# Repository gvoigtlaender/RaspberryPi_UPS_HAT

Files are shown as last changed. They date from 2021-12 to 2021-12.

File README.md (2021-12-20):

# RaspberryPi_UPS_HAT
## RaspberryPi UPS HAT, LIPO, Fan Control, I2C

## Project goals:
* provide backup battery (LiPo 3.7V) with I2C status interface
* small footprint to integrate into given RaspberrryPi case (LABISTS Starter Kit)
* integrated fan control (temperature based)
* onboard programmer interface (ISP)
* I2C based RPI ups service for Battery supervision, logging and shutdown (systemd, python3, smbus)

## Used items:
* Attiny 841 CPU
* LTC4054 LiPo Charger
* MT3606 Step-Up (LiPo > 5V)
* MIC5219 LDO (5V > 3.3V)
* USB Type-C connector
* resistors, capacitory (SMD 0805)

## Schematic:
schematic

## PCB:
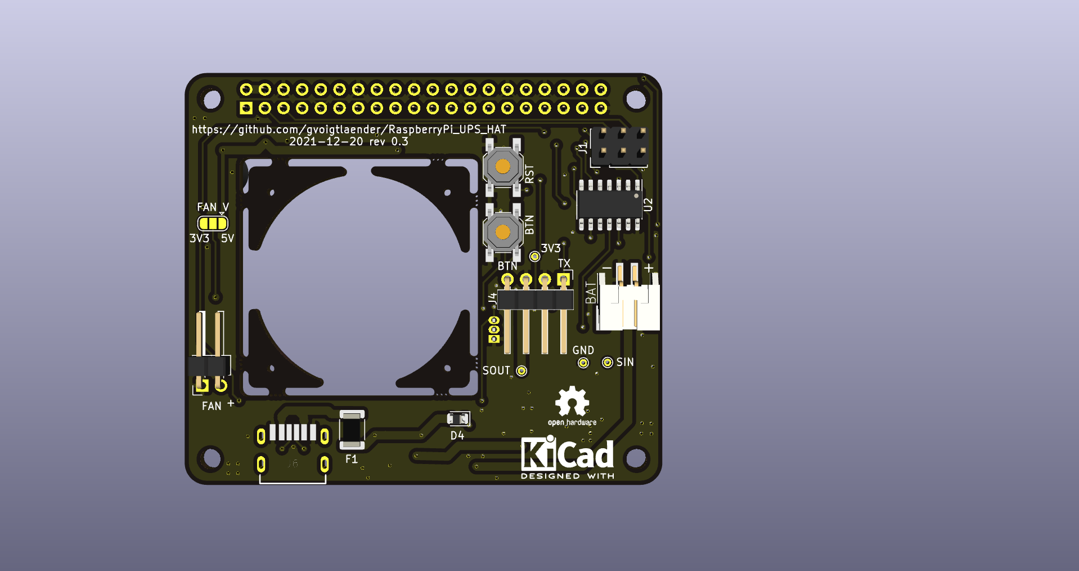
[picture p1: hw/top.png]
top view

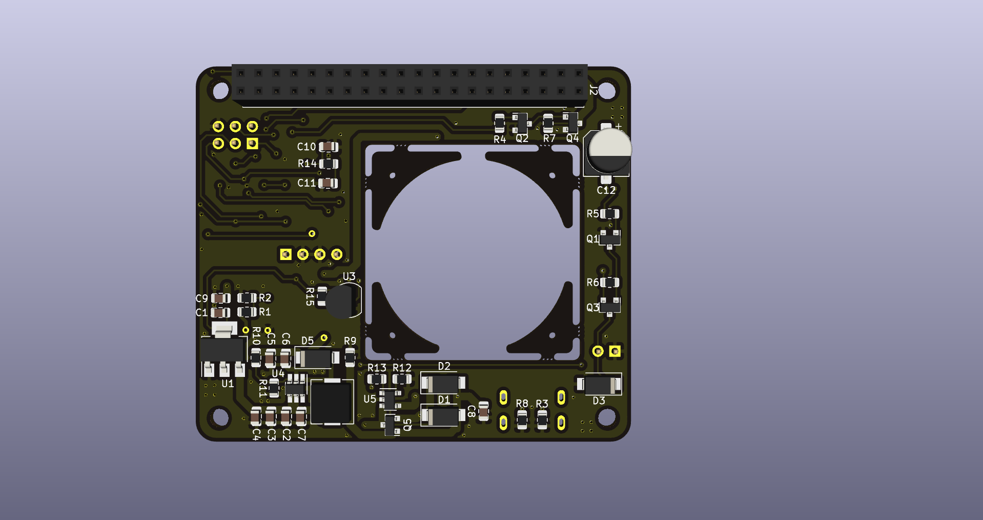
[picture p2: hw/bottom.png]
back view


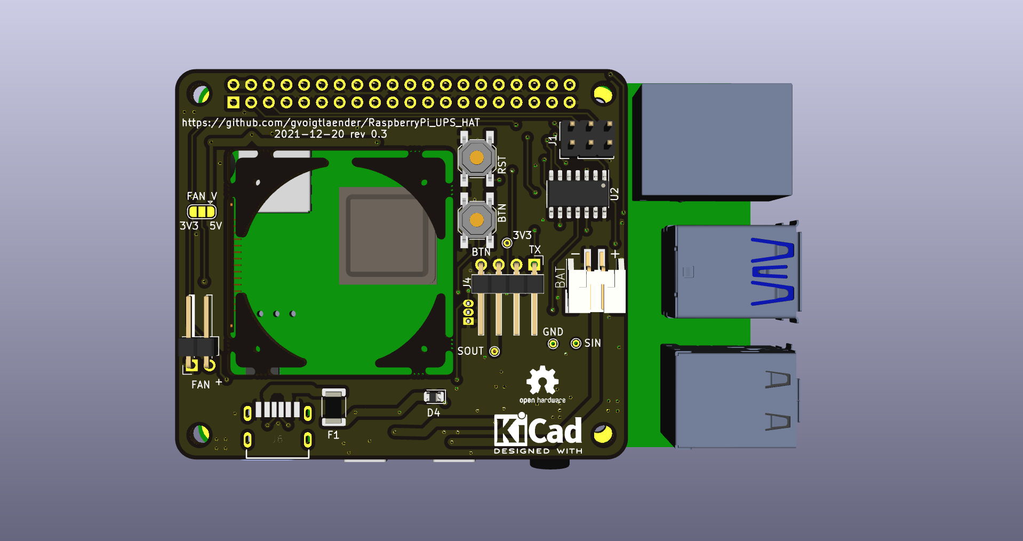
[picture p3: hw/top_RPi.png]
top view with PRi

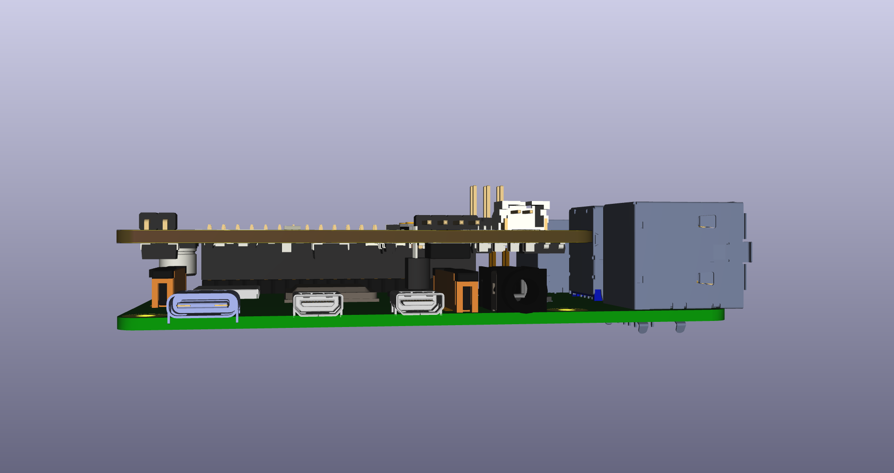
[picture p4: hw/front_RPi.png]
front view with PRi

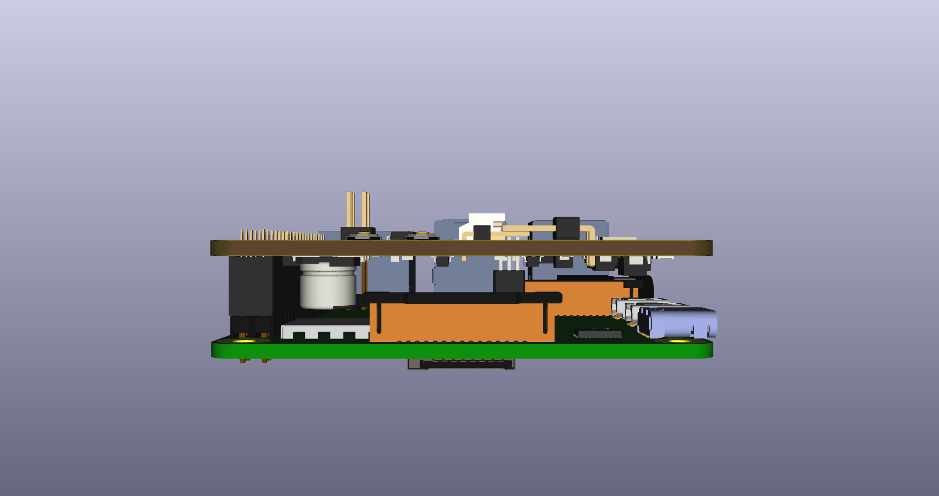
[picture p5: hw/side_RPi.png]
side view with PRi

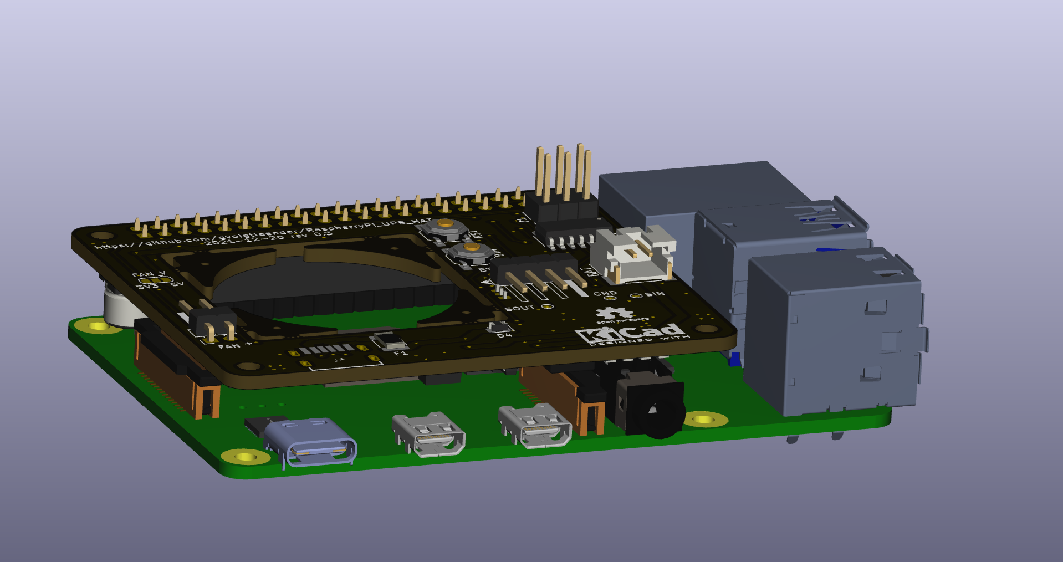
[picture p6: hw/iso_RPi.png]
iso view with PRi


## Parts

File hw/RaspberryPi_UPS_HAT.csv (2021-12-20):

Comment | Designator | Footprint | LCSC | MANUFACTURER | MAXIMUM_PACKAGE_HEIGHT | PARTREV | STANDARD
470pF | C1 | Capacitor_SMD:C_0805_2012Metric
100uF | C12 | Capacitor_SMD:CP_Elec_6.3x5.9
1uF | C2,C8,C9 | Capacitor_SMD:C_0805_2012Metric
22uF | C4,C3,C6,C5 | Capacitor_SMD:C_0805_2012Metric
100nF | C7,C10,C11 | Capacitor_SMD:C_0805_2012Metric
1N5819 | D3,D1,D5,D2 | Diode_SMD:D_SMA
LED | D4 | Diode_SMD:D_0805_2012Metric
Fuse | F1 | Fuse:Fuse_1812_4532Metric
ISP | J1 | Connector_PinHeader_2.54mm:PinHeader_2x03_P2.54mm_Vertical
Raspberry_Pi_2_3 | J2 | RaspberryPi_UPS_HAT:PinSocket_2x20_P2.54mm_Vertical_RPI
BAT | J3 | kicad_parts:JST-PH-2-SMT-RA
COM | J4 | Connector_PinHeader_2.54mm:PinHeader_1x04_P2.54mm_Horizontal
FAN | J5 | Connector_PinHeader_2.54mm:PinHeader_1x02_P2.54mm_Horizontal
USB4125-GF-A_REVA | J6 | kicad_parts:GCT_USB4125-GF-A_REVA |  | GCT | 3.16 mm | Rev A | Manufacturer Recommendations
FAN V | JP1 | Jumper:SolderJumper-3_P1.3mm_Open_RoundedPad1.0x1.5mm
6.8uH | L1 | Inductor_SMD:L_6.3x6.3_H3
BC846 | Q2,Q1 | Package_TO_SOT_SMD:SOT-23
AO3401A | Q3,Q4,Q5 | Package_TO_SOT_SMD:SOT-23
22k | R1 | Resistor_SMD:R_0805_2012Metric
14k | R11 | Resistor_SMD:R_0805_2012Metric
4k7 | R15 | Resistor_SMD:R_0805_2012Metric
33k | R2 | Resistor_SMD:R_0805_2012Metric
10k | R4,R5,R12,R13,R14 | Resistor_SMD:R_0805_2012Metric
100k | R6,R7,R10,R9 | Resistor_SMD:R_0805_2012Metric
5.1k | R8,R3 | Resistor_SMD:R_0805_2012Metric
BTN | SW1 | kicad_parts:SW_SPST_SKQG_WithoutStem
RST | SW2 | kicad_parts:SW_SPST_SKQG_WithoutStem
SIN | TP1 | TestPoint:TestPoint_THTPad_D1.0mm_Drill0.5mm
SOUT | TP2 | TestPoint:TestPoint_THTPad_D1.0mm_Drill0.5mm
GND | TP3 | TestPoint:TestPoint_THTPad_D1.0mm_Drill0.5mm
3V3 | TP4 | TestPoint:TestPoint_THTPad_D1.0mm_Drill0.5mm
AMS1117-3.3 | U1 | Package_TO_SOT_SMD:SOT-223-3_TabPin2
ATtiny841-SSU | U2 | Package_SO:SOIC-14_3.9x8.7mm_P1.27mm
DS18B20 | U3 | Package_TO_SOT_THT:TO-92_Inline
MT3608 | U4 | Package_TO_SOT_SMD:SOT-23-6_Handsoldering
TP4054 | U5 | Package_TO_SOT_SMD:SOT-23-5

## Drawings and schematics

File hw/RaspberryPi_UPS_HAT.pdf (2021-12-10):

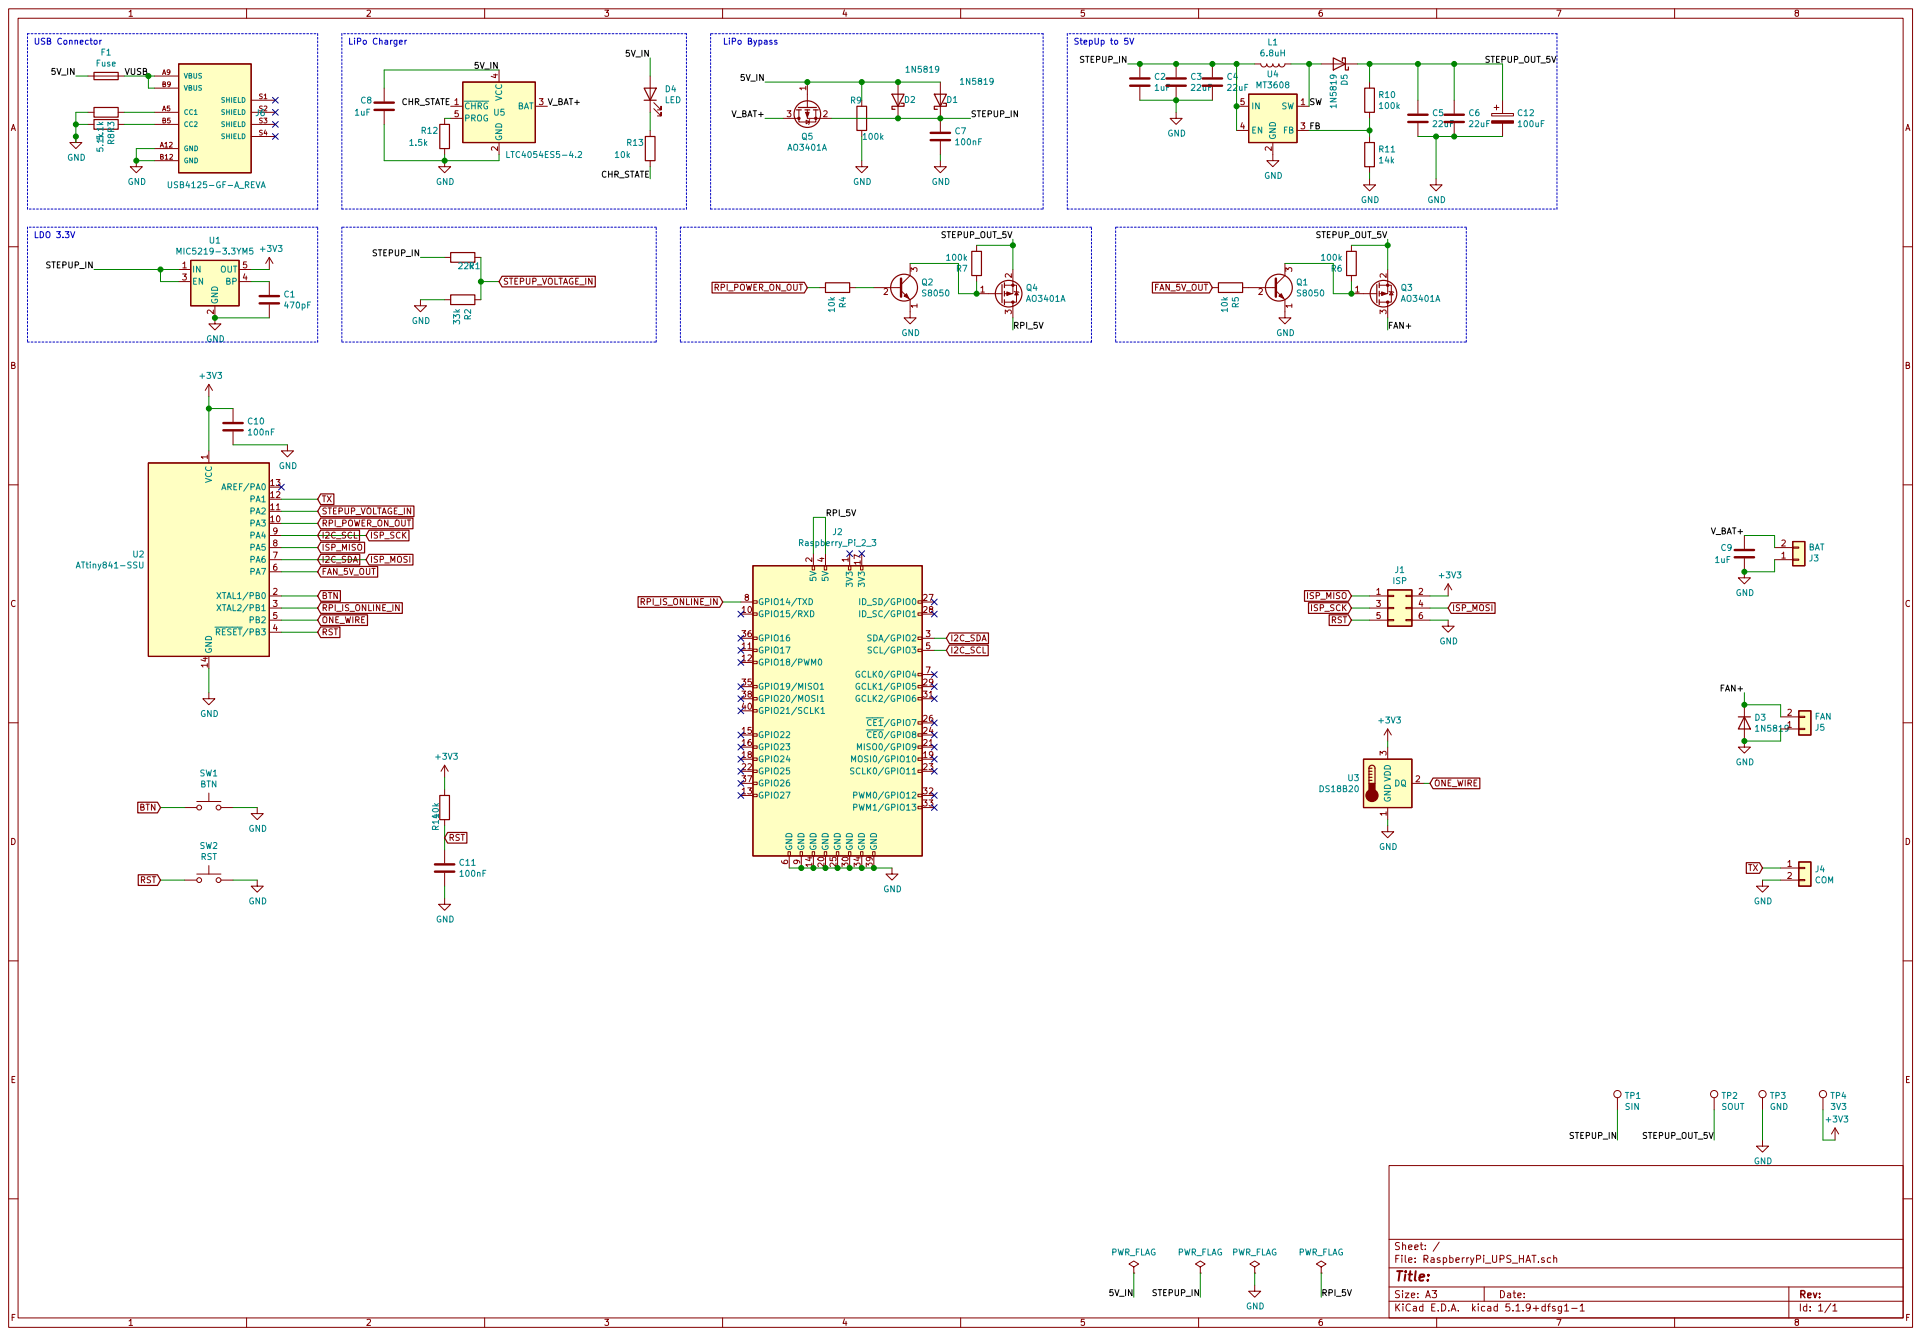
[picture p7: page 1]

1 PA3 10 PA2 11 PA1 12 AREF/PA0 13 GND 14 XTAL1/PB0 2 XTAL2/PB1 3 RESET/PB3 4 PB2 5 PA7 6 PA6 7 PA5 8 PA4 9 U2 ATtiny841-SSU

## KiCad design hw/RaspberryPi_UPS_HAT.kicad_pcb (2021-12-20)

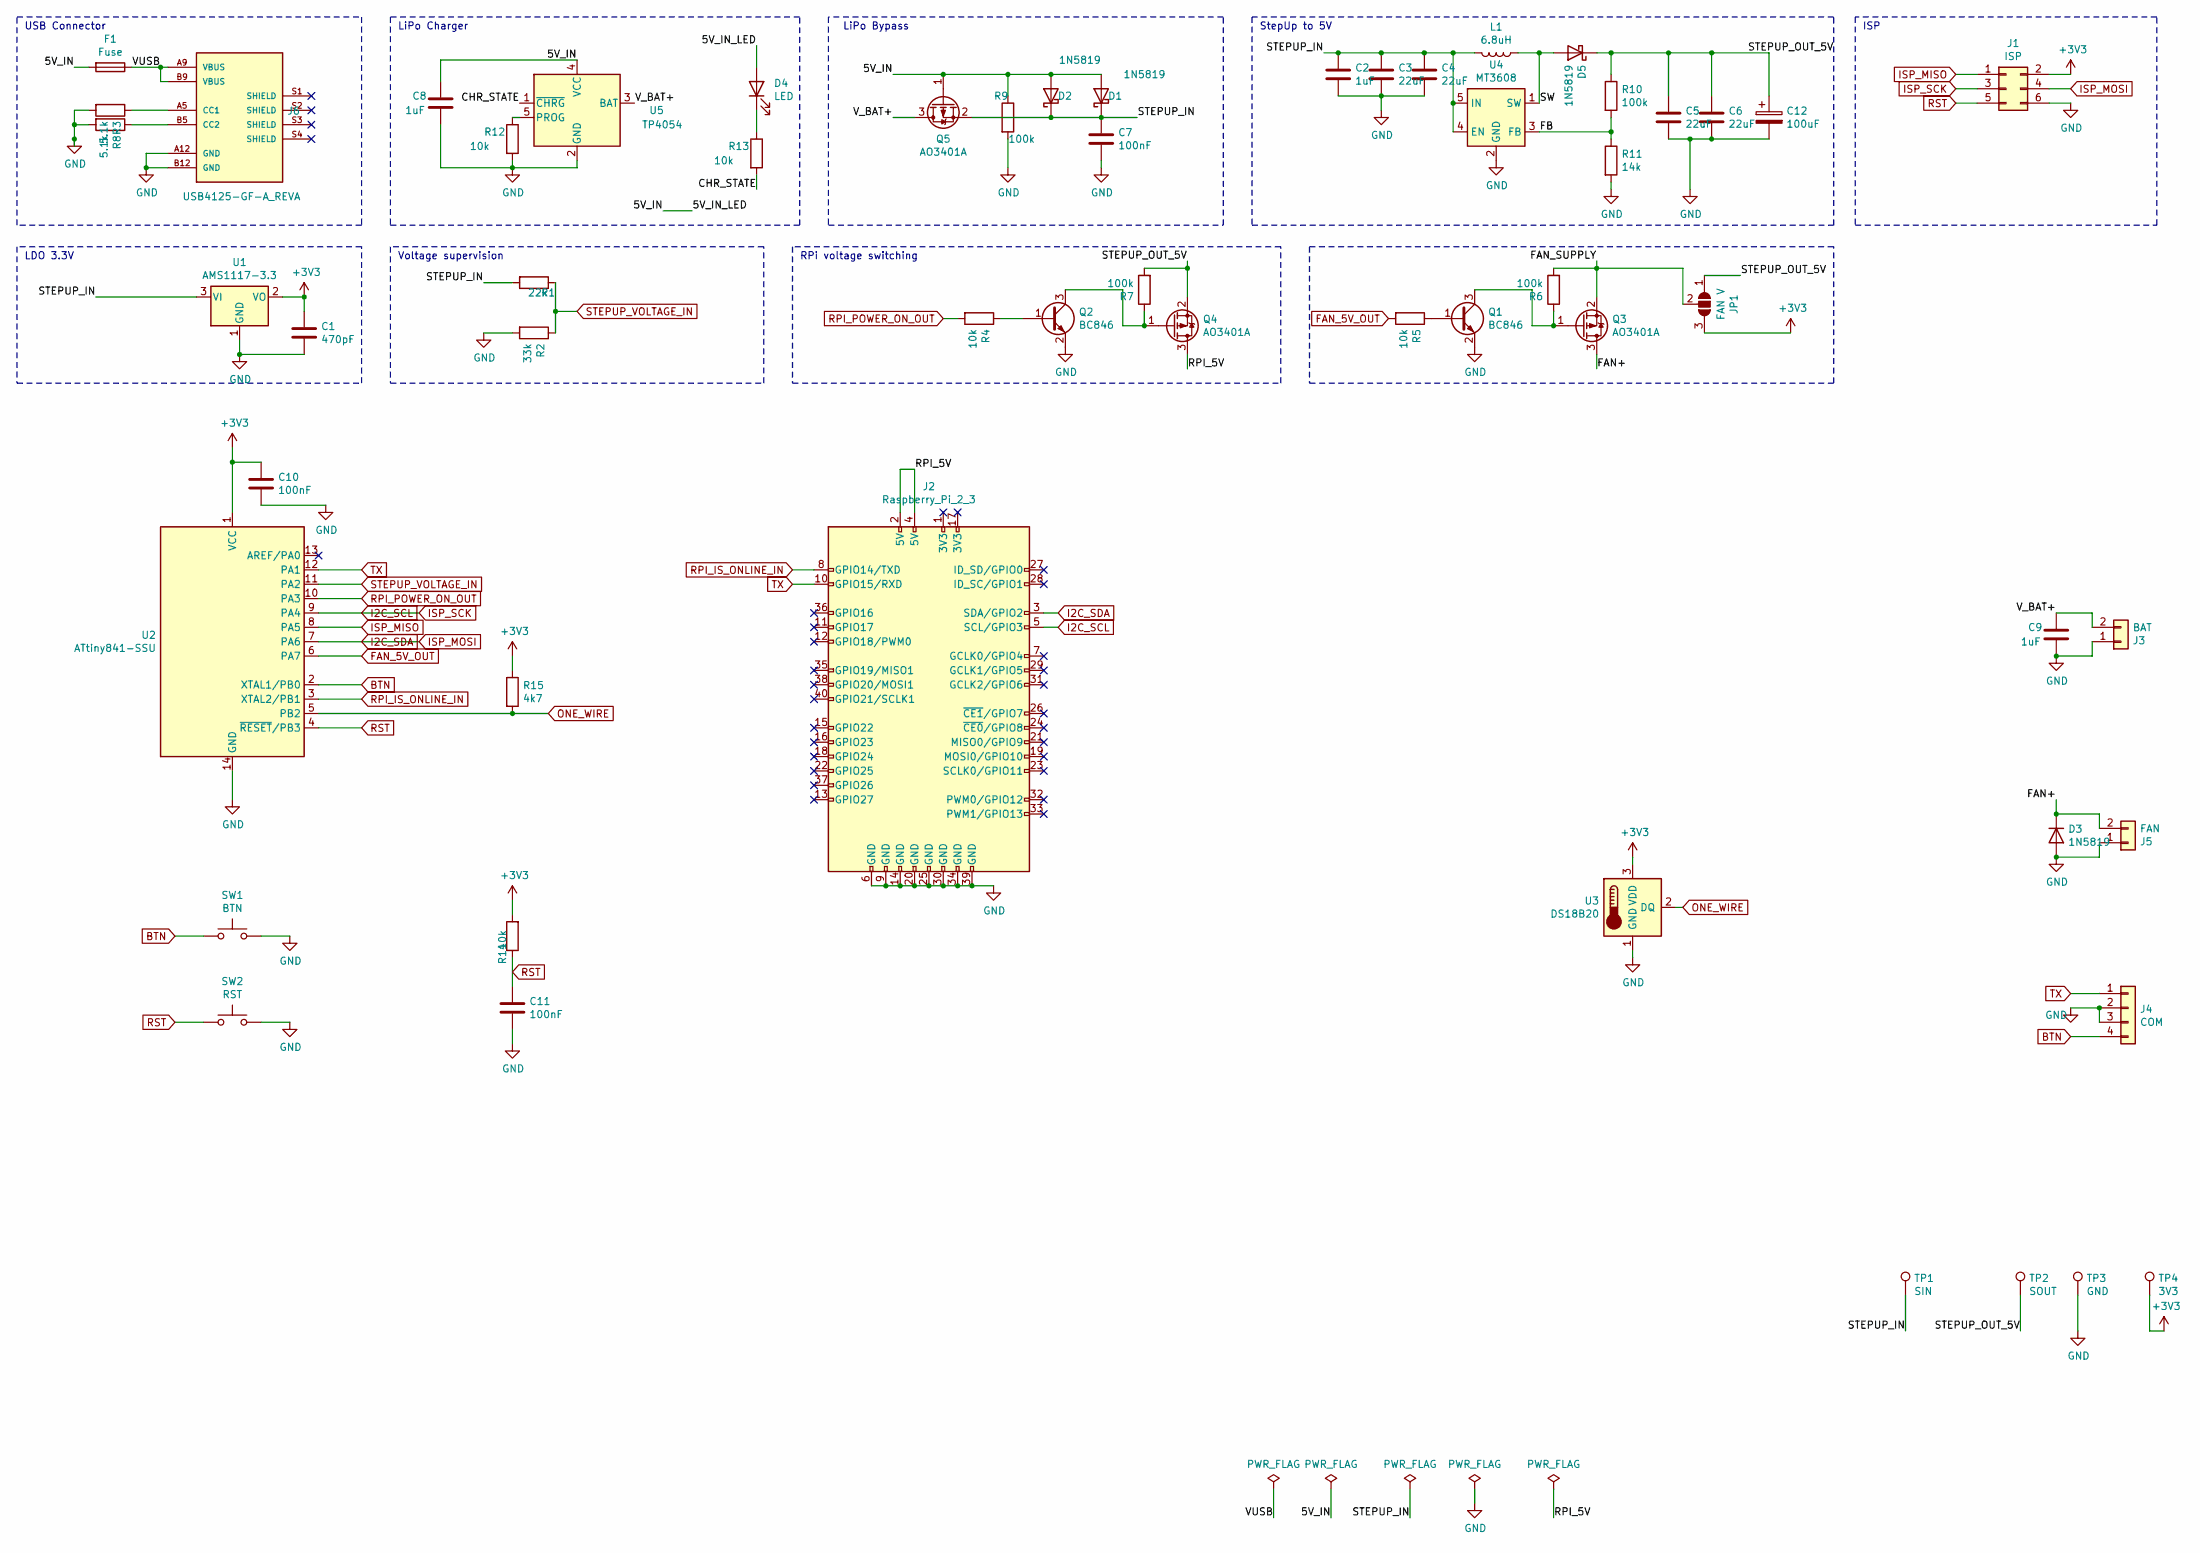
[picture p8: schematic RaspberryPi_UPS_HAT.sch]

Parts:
C1: 470pF; C_0805_2012Metric
C2, C8, C9: 1uF; C_0805_2012Metric
C3, C4, C5, C6: 22uF; C_0805_2012Metric
C7, C10, C11: 100nF; C_0805_2012Metric
C12: 100uF; CP_Elec_6.3x5.9
D1, D2, D3, D5: 1N5819; D_SMA
D4: LED; D_0805_2012Metric
F1: Fuse; Fuse_1812_4532Metric
J1: ISP; PinHeader_2x03_P2.54mm_Vertical
J2: Raspberry_Pi_2_3; PinSocket_2x20_P2.54mm_Vertical_RPI
J3: BAT; JST-PH-2-SMT-RA
J4: COM; PinHeader_1x04_P2.54mm_Horizontal
J5: FAN; PinHeader_1x02_P2.54mm_Horizontal
J6: USB4125-GF-A_REVA; GCT_USB4125-GF-A_REVA; PARTREV Rev A
JP1: FAN V; SolderJumper-3_P1.3mm_Open_RoundedPad1.0x1.5mm
L1: 6.8uH; L_6.3x6.3_H3
Q1, Q2: BC846; SOT-23
Q3, Q4, Q5: AO3401A; SOT-23
R1: 22k; R_0805_2012Metric
R2: 33k; R_0805_2012Metric
R3, R8: 5.1k; R_0805_2012Metric
R4, R5, R12, R13, R14: 10k; R_0805_2012Metric
R6, R7, R9, R10: 100k; R_0805_2012Metric
R11: 14k; R_0805_2012Metric
R15: 4k7; R_0805_2012Metric
SW1: BTN; SW_SPST_SKQG_WithoutStem
SW2: RST; SW_SPST_SKQG_WithoutStem
TP1: SIN; TestPoint_THTPad_D1.0mm_Drill0.5mm
TP2: SOUT; TestPoint_THTPad_D1.0mm_Drill0.5mm
TP3: GND; TestPoint_THTPad_D1.0mm_Drill0.5mm
TP4: 3V3; TestPoint_THTPad_D1.0mm_Drill0.5mm
U1: AMS1117-3.3; SOT-223-3_TabPin2
U2: ATtiny841-SSU; SOIC-14_3.9x8.7mm_P1.27mm
U3: DS18B20; TO-92_Inline
U4: MT3608; SOT-23-6_Handsoldering
U5: TP4054; SOT-23-5

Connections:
+3V3: C1.1, C10.1, J1.2, JP1.3 (B), R14.2, R15.1, TP4.1, U1.2 (VO), U2.1 (VCC), U3.3 (VDD)
/5V_IN: C8.1, D1.2 (A), D2.2 (A), D4.2 (A), F1.2, Q5.1 (G), R9.1, U5.4 (VCC)
/CHR_STATE: R13.2, U5.1 (~CHRG)
/FAN+: D3.1 (K), J5.2, Q3.3 (D)
/FAN_SUPPLY: JP1.2 (C), Q3.2 (S), R6.2
/FB: R10.2, R11.1, U4.3 (FB)
/RPI_5V: J2.2 (5V), J2.4 (5V), Q4.3 (D)
/STEPUP_IN: C2.1, C3.1, C4.1, C7.1, D1.1 (K), D2.1 (K), L1.2, Q5.2 (S), R1.2, TP1.1, U1.3 (VI), U4.4 (EN), U4.5 (IN)
/STEPUP_OUT_5V: C5.1, C6.1, C12.1, D5.1 (K), JP1.1 (A), Q4.2 (S), R7.2, R10.1, TP2.1
/SW: D5.2 (A), L1.1, U4.1 (SW)
/VUSB: F1.1, J6.A9 (VBUS), J6.B9 (VBUS)
/V_BAT+: C9.1, J3.2, Q5.3 (D), U5.3 (BAT)
BTN: J4.4, SW1.1, U2.2 (XTAL1/PB0)
FAN_5V_OUT: R5.2, U2.6 (PA7)
GND: C1.2, C2.2, C3.2, C4.2, C5.2, C6.2, C7.2, C8.2, C9.2, C10.2, C11.2, C12.2, D3.2 (A), J1.6, J2.6 (GND), J2.9 (GND), J2.14 (GND), J2.20 (GND), J2.25 (GND), J2.30 (GND), J2.34 (GND), J2.39 (GND), J3.1, J4.2, J4.3, J5.1, J6.A12 (GND), J6.B12 (GND), Q1.2 (E), Q2.2 (E), R2.2, R3.2, R8.2, R9.2, R11.2, R12.2, SW1.2, SW2.2, TP3.1, U1.1 (GND), U2.14 (GND), U3.1 (GND), U4.2 (GND), U5.2 (GND)
I2C_SCL: J1.3, J2.5 (SCL/GPIO3), U2.9 (PA4)
I2C_SDA: J1.4, J2.3 (SDA/GPIO2), U2.7 (PA6)
ISP_MISO: J1.1, U2.8 (PA5)
unnamed: D4.1 (K), R13.1
unnamed: J6.A5 (CC1), R3.1
unnamed: J6.B5 (CC2), R8.1
unnamed: Q1.1 (B), R5.1
unnamed: Q1.3 (C), Q3.1 (G), R6.1
unnamed: Q2.1 (B), R4.1
unnamed: Q2.3 (C), Q4.1 (G), R7.1
unnamed: R12.1, U5.5 (PROG)
ONE_WIRE: R15.2, U2.5 (PB2), U3.2 (DQ)
RPI_IS_ONLINE_IN: J2.8 (GPIO14/TXD), U2.3 (XTAL2/PB1)
RPI_POWER_ON_OUT: R4.2, U2.10 (PA3)
RST: C11.1, J1.5, R14.1, SW2.1, U2.4 (~RESET~/PB3)
STEPUP_VOLTAGE_IN: R1.1, R2.1, U2.11 (PA2)
TX: J2.10 (GPIO15/RXD), J4.1, U2.12 (PA1)

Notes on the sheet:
USB Connector
LiPo Charger
StepUp to 5V
LiPo Bypass
LDO 3.3V
Voltage supervision
RPi voltage switching
ISP

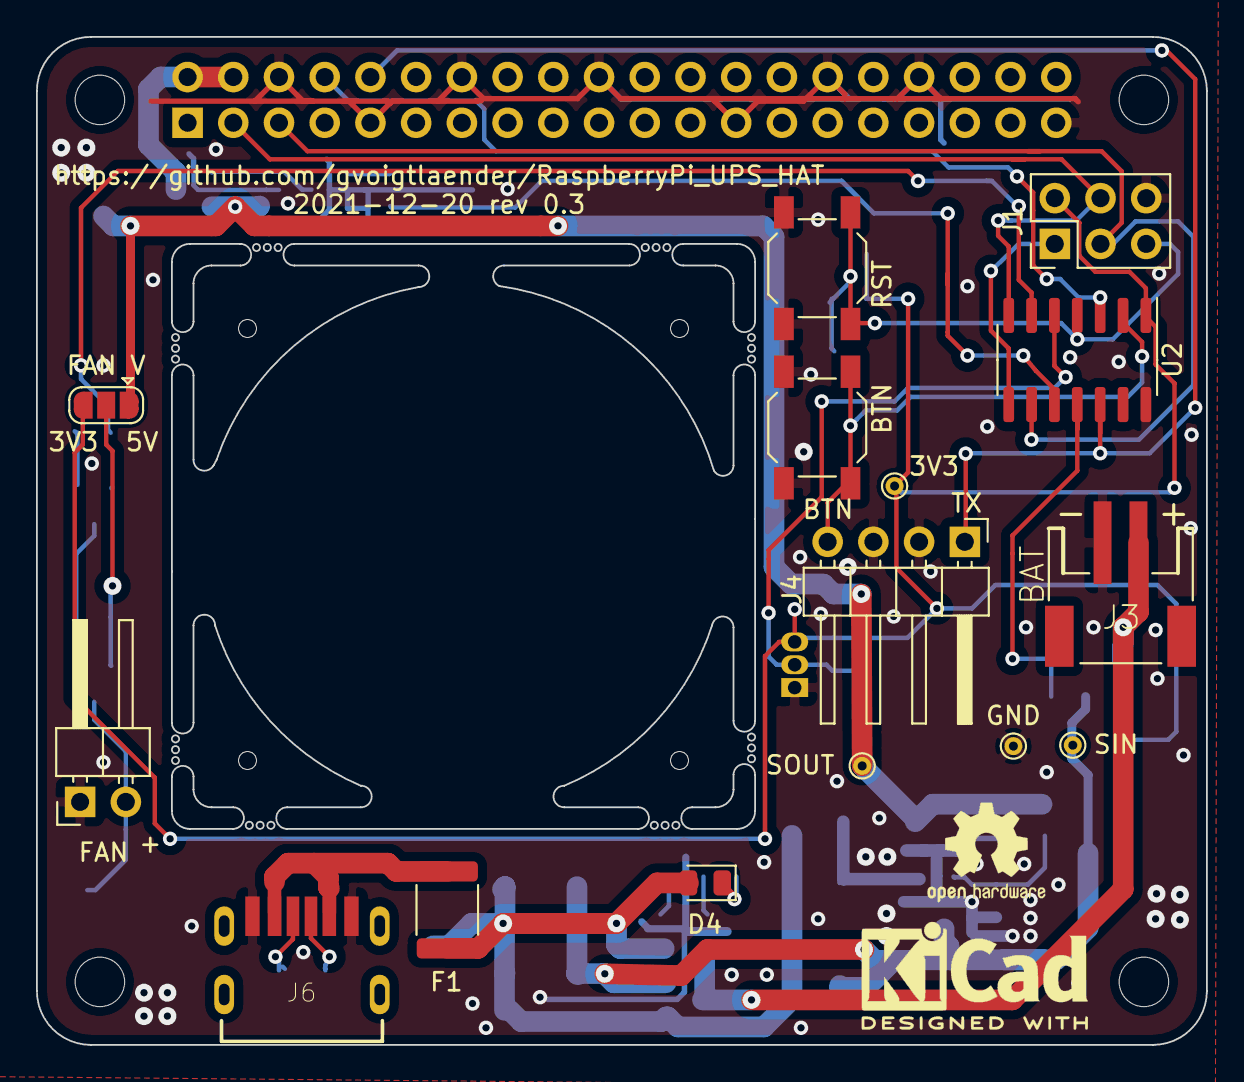
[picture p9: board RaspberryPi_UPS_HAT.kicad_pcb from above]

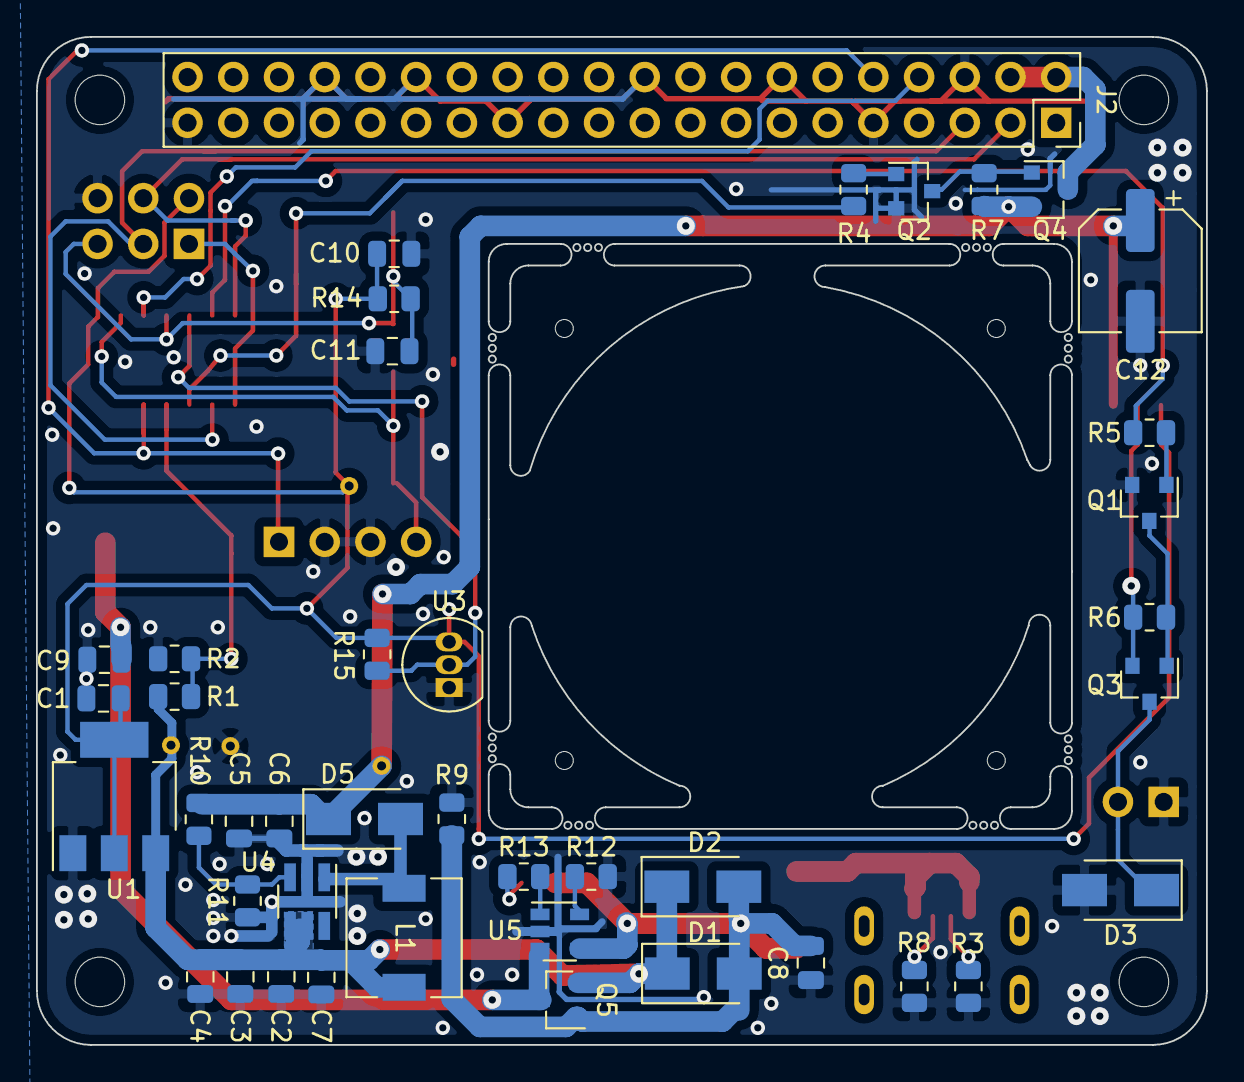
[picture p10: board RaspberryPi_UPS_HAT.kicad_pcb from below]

Board: 2 copper layers, 65.0 x 56.0 mm, 57 parts (42 on the bottom side), 32 nets.

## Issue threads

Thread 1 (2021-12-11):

RTC

gvoigtlaender, 2021-12-11:
Check if RTC can be added

gvoigtlaender, 2021-12-20:
won't implement: too complex for small footprint, not focus of project

possible solution: use ISP header to have on-top solution

Closed 2021-12-20.

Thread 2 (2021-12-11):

INA219

gvoigtlaender, 2021-12-11:
Check if INAA219 can be added

gvoigtlaender, 2021-12-20:
won't implement: too complex for small footprint, not focus of project

Closed 2021-12-20.

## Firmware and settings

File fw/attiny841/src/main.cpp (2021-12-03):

#include <Arduino.h>
#include <config.h>

#if defined USE_I2C
#include <WireS.h>
#define I2C_SLAVE_ADDRESS                                                      \
  0x4 // the 7-bit address (remember to change this when adapting this example)

#ifndef TWI_RX_BUFFER_SIZE
#define TWI_RX_BUFFER_SIZE (16)
#endif

#define tws_delay(n) delay(n)
#define WireS_stop_check()

enum _E_I2C_Data {
  eI2C_Data_Voltage_100mV = 0,   //! 4.2V = 42d
  eI2C_Data_Battery_Percent,     //! 100% = 100d
  eI2C_Data_Temperature_DegreeC, //! 42°C = 42d
  eI2C_Data_StatusBits,          //! status bits: _E_I2C_StatusBits
  eI2C_Data_TempLow,             //! lower thr temp (switch fan off)
  eI2C_Data_TempHigh,            //! higher thr temp (switch fan on)
  eI2C_LAST
};

enum _E_I2C_StatusBits {
  eI2C_SB_Button = 0x01,
  eI2C_SB_RpiOnOut = 0x02,
  eI2C_SB_RpiOnIn = 0x04,
  eI2C_SB_RpiWait = 0x08,
  eI2C_SB_FanOn = 0x10,
  eI2C_SB_AC = 0x20,
  eI2C_SB_Battery = 0x40,
  eI2C_SB_ShutdownForPowerfail = 0x80,
};

volatile uint8_t i2c_regs[eI2C_LAST] = {0, 0, 0, 0, 34, 38};
// Tracks the current register pointer position
volatile byte reg_position = 0;
// const byte reg_size = sizeof(i2c_regs);

/**
 * This is called for each read request we receive, never put more than one byte
 * of data (with TinyWireS.send) to the send-buffer when using this callback
 */
void requestEvent() {
  TinyWireS.write(i2c_regs[reg_position % eI2C_LAST]);
#if defined DEBUG
  Serial.printf("r[%d]=0x%X\n", reg_position, i2c_regs[reg_position]);
#endif
  // Increment the reg position on each read, and loop back to zero
  reg_position++;
  // if (reg_position >= eI2C_LAST) {
  //  reg_position = 0;
  //  }
}

/**
 * The I2C data received -handler
 *
 * This needs to complete before the next incoming transaction (start, data,
 * restart/stop) on the bus does so be quick, set flags for long running tasks
 * to be called from the mainloop instead of running them directly,
 */
void receiveEvent(size_t howMany) {
  if (howMany < 1) {
    // Sanity-check
    return;
  }
  if (howMany > TWI_RX_BUFFER_SIZE) {
    // Also insane number
    return;
  }

  reg_position = TinyWireS.read();
  // Serial.printf("receiveEvent(%d) idx=%d\n", howMany, reg_position);
  howMany--;
  if (!howMany) {
    // This write was only to set the buffer for next read
    return;
  }
  while (howMany--) {
    uint8_t value = TinyWireS.read();
    i2c_regs[reg_position % eI2C_LAST] = value;
    if (reg_position == eI2C_Data_TempLow) {
      Serial.print(F("TempLow="));
      Serial.println(value);
    }
    if (reg_position == eI2C_Data_TempHigh) {
      Serial.print(F("TempHigh="));
      Serial.println(value);
    }
    reg_position++;
  }
}
#else
typedef int _E_I2C_StatusBits;
#endif

void SetI2CStatusBit(_E_I2C_StatusBits bBit, bool bOn) {
#if defined USE_I2C
  if (bOn)
    i2c_regs[eI2C_Data_StatusBits] |= bBit;
  else
    i2c_regs[eI2C_Data_StatusBits] &= ~bBit;
#endif
}

bool GetI2CStatusBit(_E_I2C_StatusBits bBit) {
#if defined USE_I2C
  return ((i2c_regs[eI2C_Data_StatusBits] & bBit) == bBit);
#else
  return false;
#endif
}

#if defined USE_DS18B20_AVR
#include <bitop.h>
#include <ds18b20/ds18b20.h>
#endif

void switch_rpi(bool bOn) {
  digitalWrite(RPI_POWER_ON_OUT, bOn);
  SetI2CStatusBit(eI2C_SB_RpiWait, GetI2CStatusBit(eI2C_SB_RpiOnOut) != bOn);
  SetI2CStatusBit(eI2C_SB_RpiOnOut, bOn);
}

void switch_fan(bool bOn) {
  digitalWrite(FAN_5V_OUT, bOn);
  SetI2CStatusBit(eI2C_SB_FanOn, bOn);
}

void setup() {
  // put your setup code here, to run once:

  Serial.begin(115200);
  while (!Serial) {
    ;
  }

  Serial.printf(F("\nST\n"));

#if defined WIRE_SLAVE_ONLY
  Serial.println(F("WSO"));
#endif

  pinMode(RPI_POWER_ON_OUT, OUTPUT); // OC1B-, Arduino pin 3, ADC
  pinMode(FAN_5V_OUT, OUTPUT);       // OC1B-, Arduino pin 3, ADC

  pinMode(BTN, INPUT_PULLUP);
  pinMode(STEPUP_VOLTAGE_IN, INPUT);
  pinMode(RPI_IS_ONLINE_IN, INPUT);

#if defined USE_I2C
  TinyWireS.begin(I2C_SLAVE_ADDRESS);
  TinyWireS.onReceive(receiveEvent);
  TinyWireS.onRequest(requestEvent);
#endif

#if defined USE_DS18B20_AVR
  // set precision
  ds18b20wsp(&PORTB, &DDRB, &PINB, BIT(PB2), NULL, 0, 0, DS18B20_RES12);
  ds18b20convert(&PORTB, &DDRB, &PINB, BIT(PB2), NULL);
#endif
  // Whatever other setup routines ?
  Serial.print(F("TempLow="));
  Serial.println(i2c_regs[eI2C_Data_TempLow]);
  Serial.print(F("TempHigh="));
  Serial.println(i2c_regs[eI2C_Data_TempHigh]);

  // switch_rpi(true);
  switch_fan(true);
}

int16_t analogIn = 0;

#define ain_min 747
#define ain_max 937
#define vout_min 3.99
#define vout_max 5.01
float map_voltage(int16_t x) {
  return (x - ain_min) * (vout_max - vout_min) / (ain_max - ain_min) + vout_min;
}

#define vin_min 3.6
#define vin_max 4.2
#define pout_min 10.0
#define pout_max 100.0
float map_percent(float x) {
  if (x < vin_min)
    return pout_min;
  if (x > vin_max)
    return pout_max;
  return (x - vin_min) * (pout_max - pout_min) / (vin_max - vin_min) + pout_min;
}
void loop_ReadVoltage() {
  analogIn = analogRead(STEPUP_VOLTAGE_IN); // Read analog voltage on pin 2 (A1)
  float dVoltage = map_voltage(analogIn);
  uint8_t Voltage100mv = (uint8_t)(dVoltage * 10.0);
  i2c_regs[eI2C_Data_Voltage_100mV] = Voltage100mv;
  uint8_t Percent = (uint8_t)map_percent(dVoltage);
  i2c_regs[eI2C_Data_Battery_Percent] = Percent;
  SetI2CStatusBit(eI2C_SB_AC, dVoltage >= 4.4);
  SetI2CStatusBit(eI2C_SB_Battery, dVoltage < 4.4);
}

void loop_ReadTemperature() {
#if defined USE_DS18B20_AVR
  // static unsigned long ulMillis = millis();
  // if (millis() >= ulMillis) {
  int16_t temp;
  ds18b20read(&PORTB, &DDRB, &PINB, BIT(PB2), NULL, &temp);
  ds18b20convert(&PORTB, &DDRB, &PINB, BIT(PB2), NULL);
  uint8_t dTemperature = (uint8_t)(temp / 16.0);
// Serial.println(sensor.getTempC());
#if defined USE_I2C
  i2c_regs[eI2C_Data_Temperature_DegreeC] = dTemperature;
#endif
  //  ulMillis += 500;
  //}
#endif
}

bool bButtonReleased = false;
bool bButtonFirstReadDone = false;
void loop_ReadButton() {
  if (digitalRead(BTN) == 0) {
    //! PRESSED
    if (!bButtonFirstReadDone) {
      bButtonFirstReadDone = true;
      SetI2CStatusBit(eI2C_SB_Button, false);
    }
    if (!GetI2CStatusBit(eI2C_SB_Button)) {
      SetI2CStatusBit(eI2C_SB_Button, true);
    }
  } else {
    //! RELEASED
    if (!bButtonFirstReadDone) {
      bButtonFirstReadDone = true;
      SetI2CStatusBit(eI2C_SB_Button, true);
    }
    if (GetI2CStatusBit(eI2C_SB_Button)) {
      bButtonReleased = true;
      SetI2CStatusBit(eI2C_SB_Button, false);
    }
  }
}

void loop_ReadIsOnline() {
  SetI2CStatusBit(eI2C_SB_RpiOnIn, digitalRead(RPI_IS_ONLINE_IN) > 0);
}

void loop_SerialLog() {
  Serial.printf("[A: %d]", analogIn);
  Serial.printf("[V: %d]", i2c_regs[eI2C_Data_Voltage_100mV]);
  Serial.printf("[P: %d]", i2c_regs[eI2C_Data_Battery_Percent]);
  Serial.printf("[B: %d]", GetI2CStatusBit(eI2C_SB_Button));
  Serial.printf("[R: %d]", GetI2CStatusBit(eI2C_SB_RpiOnOut));
  Serial.printf("[O: %d]", GetI2CStatusBit(eI2C_SB_RpiOnIn));
  Serial.printf("[W: %d]", GetI2CStatusBit(eI2C_SB_RpiWait));
  Serial.printf("[F: %d]", GetI2CStatusBit(eI2C_SB_FanOn));
  Serial.printf("[T: %d]", i2c_regs[eI2C_Data_Temperature_DegreeC]);
#if defined USE_I2C
  for (uint8_t n = 0; n < eI2C_LAST; n++) {
    Serial.printf("[%02X]", i2c_regs[n]);
  }
#endif
  Serial.println();
}

//#define dTempOn 38.0
//#define dTempOff 34.0
void loop_FanControl() {
  if (millis() < 20000)
    return;
  if (i2c_regs[eI2C_Data_Temperature_DegreeC] >= i2c_regs[eI2C_Data_TempHigh]) {
    if (!GetI2CStatusBit(eI2C_SB_FanOn))
      switch_fan(true);
  } else if (i2c_regs[eI2C_Data_Temperature_DegreeC] <=
             i2c_regs[eI2C_Data_TempLow]) {
    if (GetI2CStatusBit(eI2C_SB_FanOn))
      switch_fan(false);
  }
}

#define _RPIMODE 2
enum _E_RpiState {
  eRS_Start = 0,
  eRS_WaitForRpiOn,
  eRS_WaitForRpiOff,
  eRS_Delay,
  eRS_WaitForButtonReleased,
  eRS_WaitForPowerRestored,
  eRS_Delay2,
};
_E_RpiState eRpiState = eRS_Start;
#define nRpiOffDelay 5000
void loop_RpiControl() {
#if _RPIMODE == 1
  if (bWaitForStateChange) {
    if (bIsOnline == bRpi)
      bWaitForStateChange = false;
  } else if (bRpi) {
    if (!bIsOnline)
      switch_rpi(false);
  } else if (bButtonReleased) {
    switch_rpi(true);
  }

#else  // _RPIMODE

  static unsigned long ulMillis = millis();
  switch (eRpiState) {
  case eRS_Start:

    if (!GetI2CStatusBit(eI2C_SB_AC)) {
      SetI2CStatusBit(eI2C_SB_ShutdownForPowerfail, true);
      eRpiState = eRS_WaitForPowerRestored;
      Serial.printf(F("l_Rc, sr(0), "
                      "s=W4AC\n"));
      break;
    }
    // Serial.printf("loop_RpiControl, state=eRS_Start\n");
    Serial.printf(F("l_Rc, s=W4R1\n"));
    switch_rpi(true);
    eRpiState = eRS_WaitForRpiOn;
    break;

  case eRS_WaitForRpiOn:
    if (GetI2CStatusBit(eI2C_SB_RpiOnIn)) {
      Serial.printf(F("l_Rc, o1, s=W4R0\n"));
      eRpiState = eRS_WaitForRpiOff;
    }
    break;

  case eRS_WaitForRpiOff:
    if (!GetI2CStatusBit(eI2C_SB_RpiOnIn)) {
      Serial.printf(F("l_Rc, o0, s=D\n"));
      ulMillis = millis() + nRpiOffDelay;
      eRpiState = eRS_Delay;
    }
    break;

  case eRS_Delay:
    if (GetI2CStatusBit(eI2C_SB_RpiOnIn)) {
      Serial.printf(F("l_Rc, o1, s=W4R0\n"));
      eRpiState = eRS_WaitForRpiOff;
      break;
    }

    if (millis() <= ulMillis)
      break;

    Serial.printf(F("l_Rc, sr(0), "
                    "s=W4B0\n"));
    switch_rpi(false);

    if (GetI2CStatusBit(eI2C_SB_Battery)) {
      SetI2CStatusBit(eI2C_SB_ShutdownForPowerfail, true);
      eRpiState = eRS_WaitForPowerRestored;
      Serial.printf(F("l_Rc, sr(0), "
                      "s=W4AC\n"));
      break;
    }

    eRpiState = eRS_WaitForButtonReleased;
    break;

  case eRS_WaitForButtonReleased:
    if (bButtonReleased == false)
      break;

    Serial.printf(F("l_Rc, B0, sr(1), "
                    "s=W4R1\n"));
    switch_rpi(true);
    eRpiState = eRS_WaitForRpiOn;
    break;

  case eRS_WaitForPowerRestored:
    if (!GetI2CStatusBit(eI2C_SB_AC)) {
      break;
    }

    ulMillis = millis() + nRpiOffDelay;
    eRpiState = eRS_Delay2;
    break;

  case eRS_Delay2:
    if (!GetI2CStatusBit(eI2C_SB_AC)) {
      ulMillis = millis() + nRpiOffDelay;
      break;
    }

    if (millis() <= ulMillis)
      break;

    Serial.printf(F("l_Rc, s=W4R1\n"));
    switch_rpi(true);
    eRpiState = eRS_WaitForRpiOn;
    break;

  default:
    eRpiState = eRS_WaitForRpiOn;
    break;
  }
#endif // _RPIMODE
}

void loop() {
  // put your main code here, to run repeatedly:

  loop_ReadButton();

  static unsigned long ulMillis = millis();
  if (millis() >= ulMillis) {
    loop_FanControl();
    loop_ReadTemperature();
    loop_ReadIsOnline();
    loop_ReadVoltage();
    loop_SerialLog();
    ulMillis += 500;
  }
  loop_RpiControl();
  bButtonReleased = false;

#if defined USE_I2C
  WireS_stop_check();
#endif
}

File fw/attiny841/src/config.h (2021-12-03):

#if !defined _CONFIG_H_
#define _CONFIG_H_

#define USE_I2C
#define USE_DS18B20_AVR
#define HW_REV 1

#if HW_REV == 1
#define STEPUP_VOLTAGE_IN PIN_A2
#define RPI_POWER_ON_OUT PIN_PA3
#define FAN_5V_OUT PIN_PA7
#define BTN PIN_PB0
#define RPI_IS_ONLINE_IN PIN_PB1
#define ONE_WIRE PIN_PB2
#elif HW_REV == 2
#define RPI_POWER_ON_OUT PIN_PA2
#define FAN_5V_OUT PIN_PA3
#define ONE_WIRE PIN_PA7
#define BTN PIN_PB0
#define RPI_IS_ONLINE_IN PIN_PB1
#define STEPUP_VOLTAGE_IN PIN_PB2
#endif

#endif // _CONFIG_H_

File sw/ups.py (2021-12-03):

#!/usr/bin/python
import smbus
import time
import os
import syslog
import sys
from datetime import datetime
bus = smbus.SMBus(1)
address = 0x04
warn = 0
ncnt = 0

bus.write_byte_data(address, 4, 38)
bus.write_byte_data(address, 5, 45)


logfile = '/var/log/Raspi_UPS_HAT.log'
syslog.openlog(sys.argv[0])

def log(msg, bsyslog):
	print(msg)
	file = open(logfile,"a")
	file.write("%s: %s\n" % (time.strftime("%d.%m.%Y %H:%M:%S"), msg))
	file.close
	if bsyslog:
		syslog.syslog(msg)


while True:
	cap_min = 25
	bsyslog = ncnt % 1000 == 0
	ncnt =ncnt + 1
	now = datetime.now()
	dt_string = now.strftime("%d/%m/%Y %H:%M:%S")
	log("date and time ="+ dt_string, bsyslog)
	data = 0
	bus.write_byte(address, 0)
	voltage = bus.read_byte_data(address, 0)
	# print voltage
	capacity = bus.read_byte_data(address, 1)
	temperature = bus.read_byte_data(address, 2)
	status = bus.read_byte_data(address, 3)
	batmode = (status & 0x40 > 0);
	log("voltage %.1fV" % (voltage/10.0),bsyslog or batmode)
	log("capacity %.0f%%" % capacity,bsyslog or batmode);
	log("temperature: %.0fC" % temperature,bsyslog)
	log("button %d" % (status & 0x01 > 0),bsyslog)
	log("fan %d" % (status & 0x10 > 0),bsyslog)
	log("ac %d" % (status & 0x20 > 0),bsyslog)
	log("battery %d" % batmode,bsyslog)
	if capacity < cap_min and batmode == 1:
		warn = warn + 1
	if  warn == 1:
		log("shutting down", 1)
		time.sleep(1)
		os.system('shutdown -h now')
	time.sleep(1)

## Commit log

2021-12-03 update: move defines to config.h update: im/export thr TempLow/-High via I2C
2021-12-12 add BOM & gerber files
    [RaspberryPi_UPS_HAT-B_Cu.gbr, RaspberryPi_UPS_HAT-B_Mask.gbr, RaspberryPi_UPS_HAT-B_Paste.gbr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]
2021-12-17 update: make BTN available as optional pin header
    [RaspberryPi_UPS_HAT-B_Cu.gbr, RaspberryPi_UPS_HAT-B_Mask.gbr, RaspberryPi_UPS_HAT-B_Paste.gbr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]
2021-12-17 update pictures
    [RaspberryPi_UPS_HAT.sch]
2021-12-20 update: rev0.3 - new alignmant, LCSC listed elements
    [RaspberryPi_UPS_HAT-B_Cu.gbr, RaspberryPi_UPS_HAT-B_Mask.gbr, RaspberryPi_UPS_HAT-B_Paste.gbr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]
2021-12-20 update: graphics for rev 0.3
    [RaspberryPi_UPS_HAT.kicad_pcb]
